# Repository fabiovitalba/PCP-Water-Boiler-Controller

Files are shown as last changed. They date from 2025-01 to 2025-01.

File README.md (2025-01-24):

# Fabio Vitalba - Arduino Water Boiler Controller ('Boil Voyage')
This is the final project for the course "Physical Computing Project 24/25" for Fabio Vitalba.

## Boil Voyage
The Project is divided into two repositories. This repository is the Arduino Controller that controls the 3D world created in Unity.
Find the other repository here: [Ship Navigation Project (Boil Voyage)](https://github.com/fabiovitalba/PCP-Ship-Project).

## 1. Description
This Arduino Project consists in the arduino script that handles the Water Boiler Controller. It reads from three different sensors/resistors:
- A **rotary potentiometer** that is hidden in the bottom part of the water boiler. It is used in order to read the rotation of the water boiler.
- A **photocell** that is placed inside the water boiler in order to read the amount of light shining into the inside of the water boiler. This is used to measure how much light is led in by the water boiler lid.
- A **switch** directly taken from the water boiler circuit. The switch consists in a broken circuit that closes whenever the button on the handle of the water boiler is closed.

These inputs are used to produce the following outputs:
- **SensorAbsoluteRotationValue**: The raw output produced by the rotary potentiometer, filtered using EMA (Exponential Moving Average).
- **AbsoluteRotationValue**: The absolute rotation of the water boiler. This is the processed output produced by the rotary potentiometer.
- **RelativeRotationValue**: The rotation of the water boiler, relative to its starting position. The starting position is also continuously updated, so that anytime the user reverses the rotation, that reversal is immediately effective.
- **SwitchValue**: The output produced by the switch circuit. Whenever the switch is not being pressed this will be 0. However, when the switch is being pressed, the circuit closes and the value will raise.
- **SensorLightValue**: The raw output produced by the photocell.
- **LightValue**: The output produced by the photocell. Whenever the lid is closed a base-amount of light is entering the water boiler from the sidewalls. Once the lid is opened (even when only partially open), more light enters and the output of the photocell will raise.

## 2. Visuals
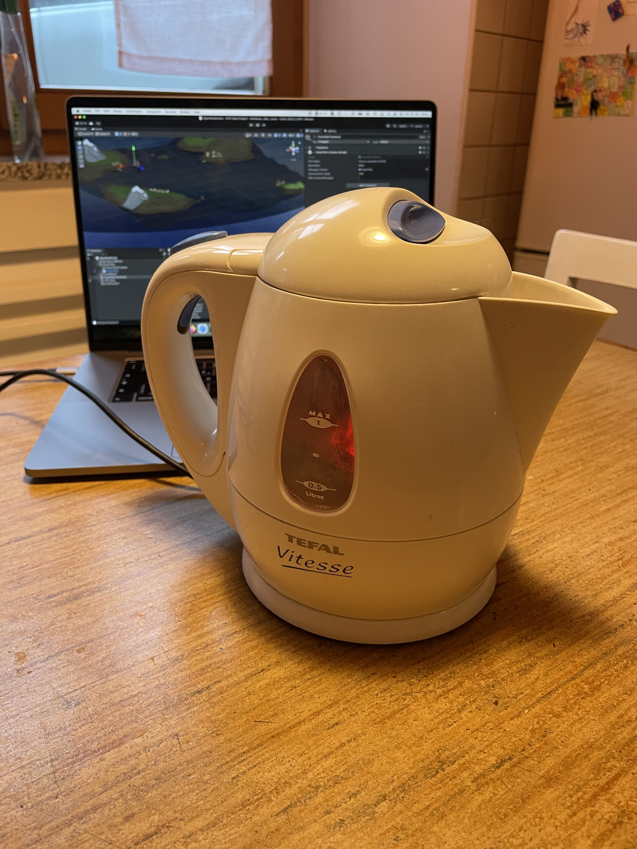
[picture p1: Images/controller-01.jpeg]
Image of the Controller package

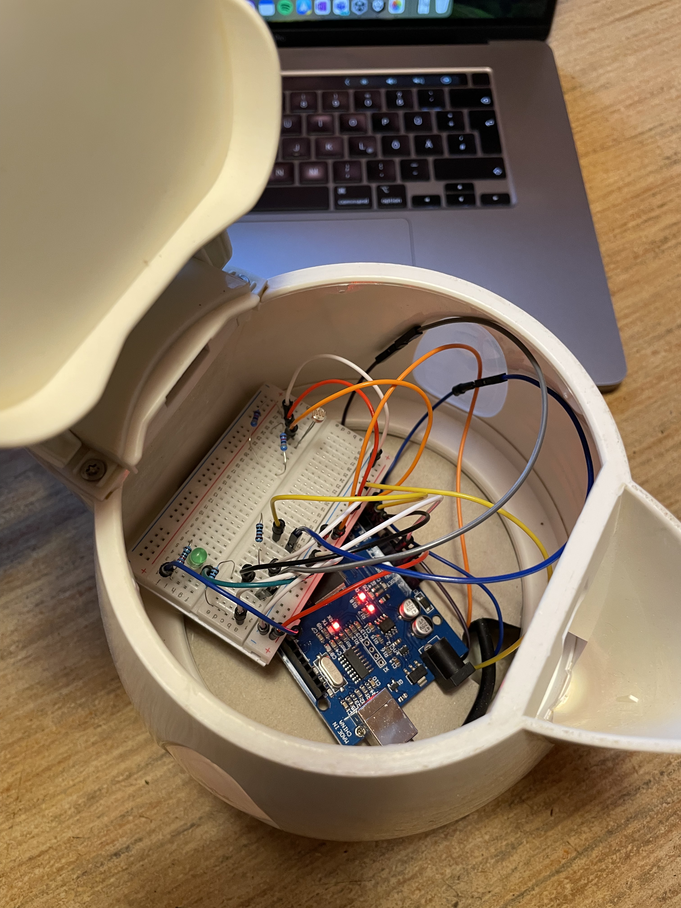
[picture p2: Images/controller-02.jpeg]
Image of the Controller insides

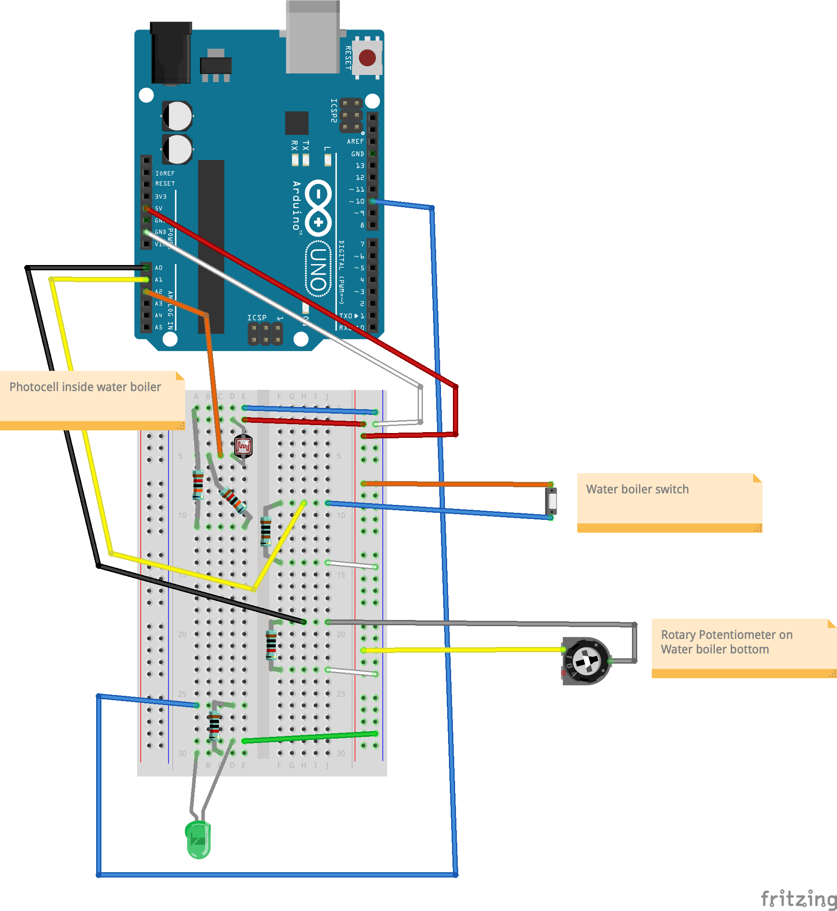
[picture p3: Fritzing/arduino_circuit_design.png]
Circuit design in fritzing


Find some more detailed images of the [build process](/BUILDHISTORY.md).

## 3. Installation
The Water Boiler Controller can be used as is, but should be tuned based on the environment it's being used in. The arduino script contains a few constants that should be tuned based on the baseline values you might find during usage.

### 3.1. Rotation settings
_In order to tune these settings, listen to the Arduino on the Serial Port (default is 9600). Open the Serial Plotter, then continue._
- `MIN_ROTATION_VALUE`: Rotate the water boiler completely to the left. Read the value for `SensorAbsoluteRotationValue` and set the constant `MIN_ROTATION_VALUE` to this value. (Rounding the value up a little is fine.)
- `MAX_ROTATION_VALUE`: Rotate the water boiler completely to the right. Read the value for `SensorAbsoluteRotationValue` and set the constant `MIN_ROTATION_VALUE` to this value. (Rounding the value down a little is fine.)
- `MAX_REL_ROTATION_VALUE`: This value defines the maximum rotation value before the relative starting position is moved in the rotation direction. A higher value means that rotations are harder to reverse, a smaller value means that rotations are quick to reverse. Default value is `40`.

### 3.2. Switch settings
_In order to tune these settings, listen to the Arduino on the Serial Port (default is 9600). Open the Serial Plotter, then continue._
- `SWITCH_TRIGGER_VALUE`: This is the minimum value for the Switch Circuit to count as "triggered". Usually the switch - in unpressed mode - should have a value of 0, so anything above 0 should mean that the switch is triggered. To avoid unwanted behaviour, we set a theshold in order to be sure that the switch was triggered correctly. Default value is `300`.

### 3.3. Light settings
_In order to tune these settings, listen to the Arduino on the Serial Port (default is 9600). Open the Serial Plotter, then continue._
- `MIN_LIGHT_VALUE`: Place the water boiler in the position you want to use it and close the water boiler lid. Read the value for `SensorLightValue` and set the constant `MIN_LIGHT_VALUE` to this value. It is a good idea to add 10-20 to the constant's value to account for slight lighting variations.
- `MAX_LIGHT_VALUE`: Place the water boiler in the position you want to use it and open the water boiler lid completely. Read the value for `SensorLightValue` and set the constant `MAX_LIGHT_VALUE` to this value. (Rounding the value down a little is fine.)

## 4. Usage
The Water Boiler Controller emits the following values on the Serial Port (default 9600):
- **AbsoluteRotationValue**: Provides a value between `-127` and `127` to indicate the absolute rotation position for the rotary potentiometer. The value `127` is at the outer left maximum, while the value `-127` is at the outer right maximum.
- **RelativeRotationValue**: Provides a value between `-MAX_REL_ROTATION_VALUE` and `MAX_REL_ROTATION_VALUE` relative to the starting position of the controller. Negative value indicate a rotation to the right, positive a rotation to the left.
- **SwitchValue**: Provides a value between `0` and `1`. Anything that is above `SWITCH_TRIGGER_VALUE` activates the internal LED and should be counted as triggered/active.
- **LightValue**: Provides a value between `0` and `255`. The higher the value, the more light is entering the water boiler.

Sample output: `SensorAbsoluteRotationValue:473.00,AbsoluteRotationValue:-31,RelativeRotationValue:0,SwitchValue:0,SensorLightValue:519.00,LightValue:0`

## 5. Support
For issues feel free to contact me on fvitalba@unibz.it, or by opening an Issue on the Repository.

## 6. Contributing
Currently this project is not open for contributions at it is in very early stages of development.

## 7. Authors and acknowledgment
- Main author: Fabio Vitalba

## 8. License
MIT License
Copyright (c) 2025 Fabio Vitalba

## 9. Project status
This Project is currently being worked on.

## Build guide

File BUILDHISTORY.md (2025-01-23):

# Build History
This photoseries gives a little insight into the build process of the water boiler controller.

### Reassembled water boiler
I removed all the insides from the water boiler and the heating circuit. The switch circuit was partially kept and cables were soldered on. The rotar potentiometer was glued to the underside of the water boiler switch.
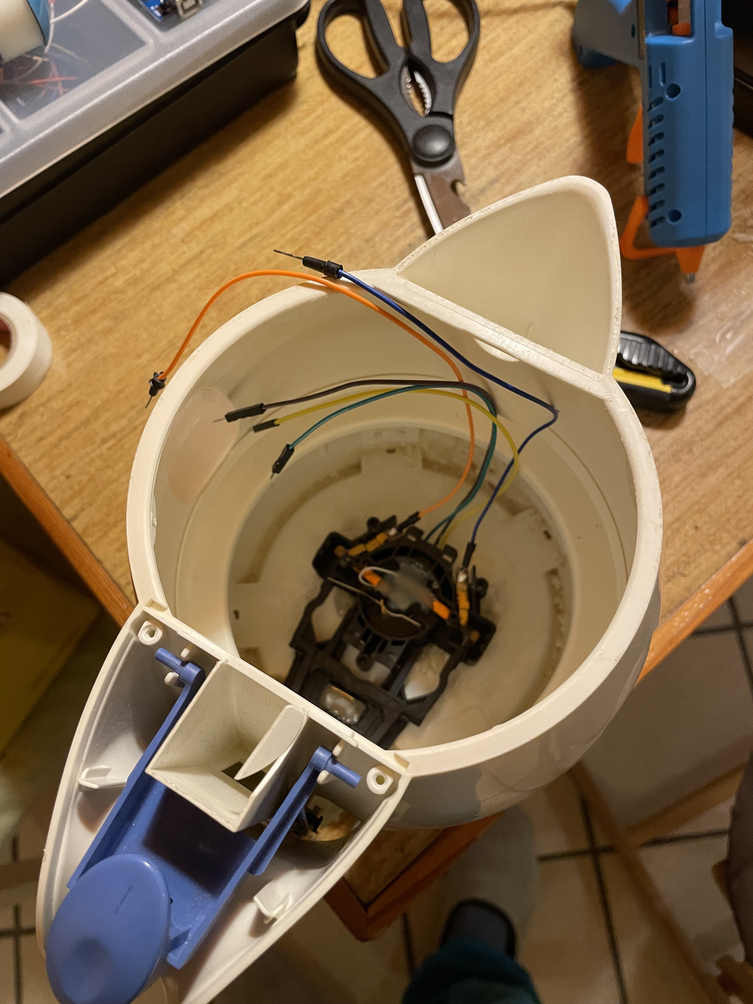
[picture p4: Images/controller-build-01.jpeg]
Reassembled water boiler with switch and rotary potentiometer


### Rotary potentiometer at the bottom
The rotary potentiometer was placed at the bottom of the water boiler instead of its power supply. Two wires were put in place in order to give the potentiometer something to hold on to. The wires were later glued in place to avoid them falling out.
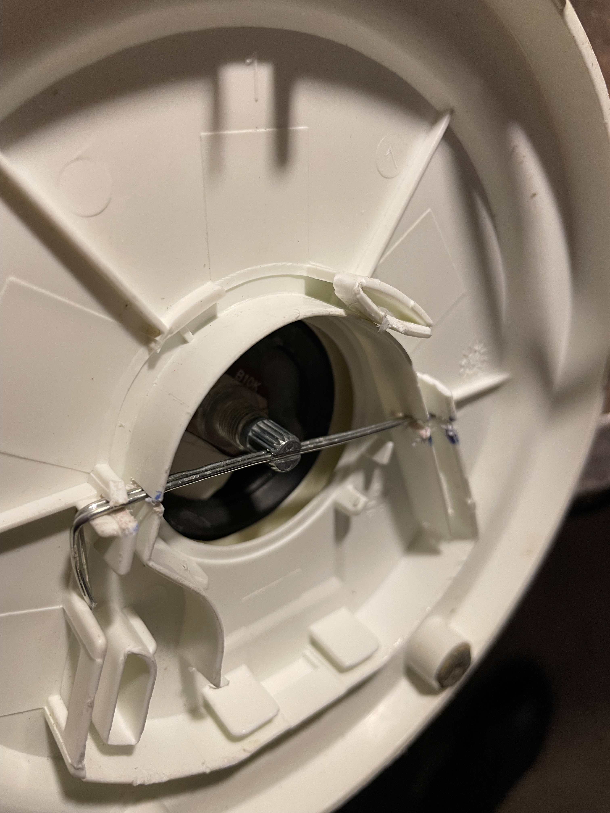
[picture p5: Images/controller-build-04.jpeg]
Rotary potentiometer at the bottom


### Water boiler switch circuit
The water boiler switch circuit is very simple as it uses a plastic lever to connect the copper contacts to close the circuit. Two cables were soldered onto the copper contacts in order to read the closing of this circuit whenever the button closes.
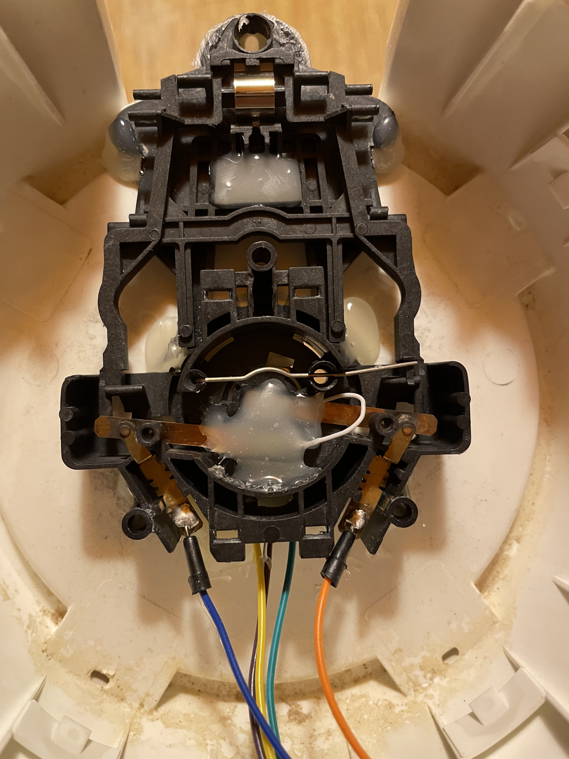
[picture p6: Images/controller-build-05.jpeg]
Water boiler switch circuit


### Arduino prototyping
The arduino was connected with the rotary potentiometer, and the switch in order to test first outputs.
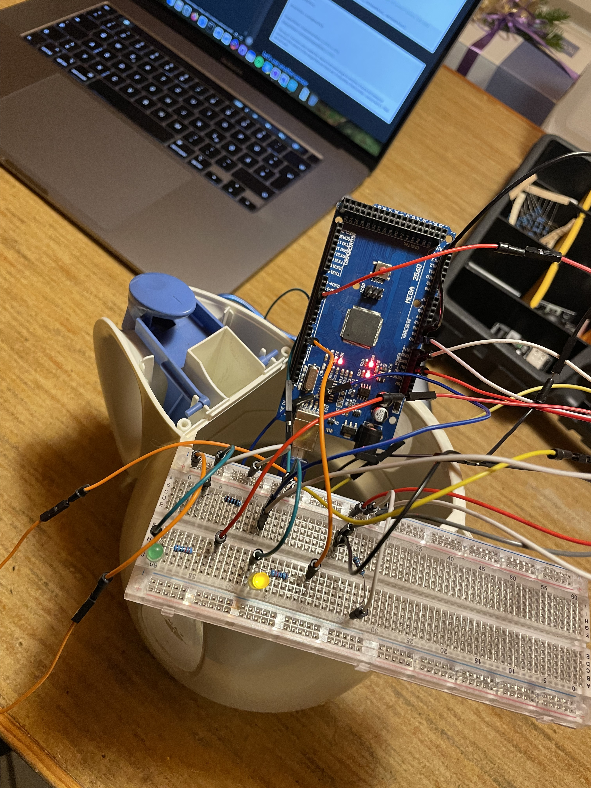
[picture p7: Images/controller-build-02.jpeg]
Prototyping with Arduino


### USB cable positioning
The USB cable was positioned at the very bottom of the water boiler handle in order to achieve a clean look, without immediately giving away the insides.
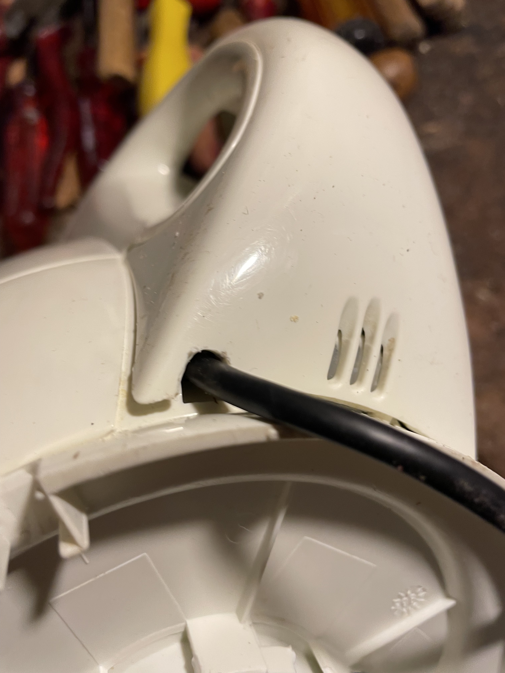
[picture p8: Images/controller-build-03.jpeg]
USB cable exit on water boiler


### Water boiler insides cleanup
Instead of the water boilers aluminium plate, which could not be kept since it contained the heating circuit and was simply too large, a cardboard piece was placed to hide the switch and provide a layer for the arduino to sit on.
Cables are funneled from the bottom through a small hole in the cardboard.
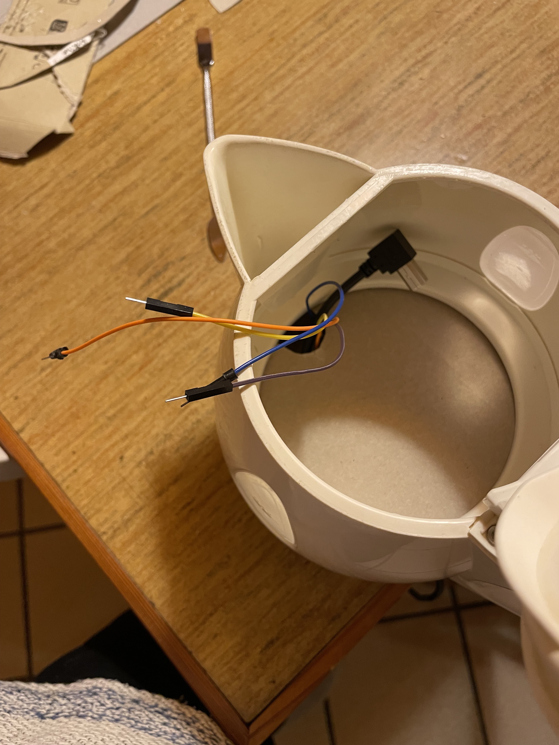
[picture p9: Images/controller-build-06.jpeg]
Cardboard layer to hide switch


### Arduino placed on the inside
The Arduino is placed on the cardboard layer and connected with a mini breadboard that contains all the necessary circuits to read the outputs. A photocell was added in order to read the incoming light and provide additional outputs.
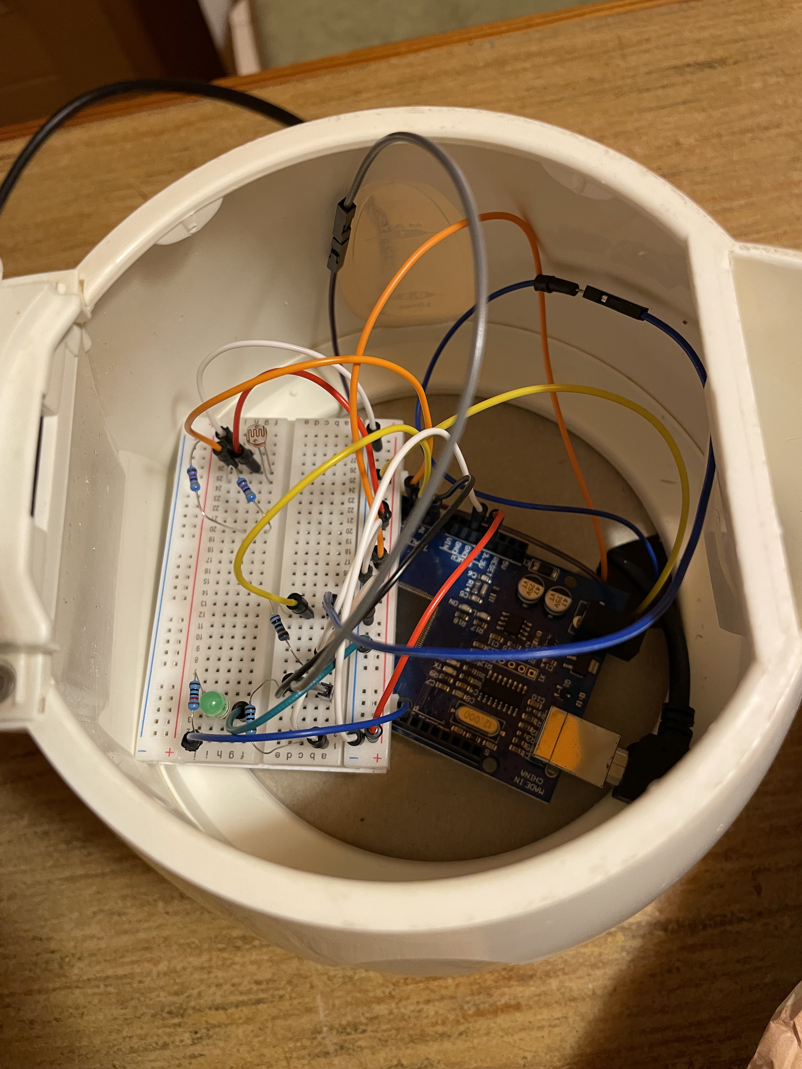
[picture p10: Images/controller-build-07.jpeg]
Arduino placed on the inside


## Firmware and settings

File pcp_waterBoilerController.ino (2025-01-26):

/// LAYOUT BASED PARAMETERS ///
const int SWITCH_PIN = A1;
const int ROTATION_PIN = A0;
const int LIGHT_PIN = A2;
const int LED_PIN = 10;


/// ENVIRONMENT RELATIVE PARAMETERS ///
// Values read by analog pins are voltages between 0V and 5V.
// 0V corresponds to 0 and 5V corresponds to 1023.
const int MIN_ROTATION_VALUE = 380;
const int MAX_ROTATION_VALUE = 640;
const int MAX_REL_ROTATION_VALUE = 40;

// The switch can assume values between 0 and ~600-700.
// We assume that a minimum value (like 300) has to be met in order to count as active.
const int SWITCH_TRIGGER_VALUE = 300;

// In absolute darkness the light sensor still return about ~500 (~580 with the lid closed) as a value.
// At maximum brightness the light sensor reaches about ~660  (with the lid open and beneath a lamp).
const int MIN_LIGHT_VALUE = 580;
const int MAX_LIGHT_VALUE = 660;


/// RELATIVE PARAMETERS ///
int startingRotationValue = 0;


/// FILTER PARAMETERS ///
const float ALPHA = 0.1f; // The higher the value, the more we weigh recently read data.
int emaFilteredValue = 0;


void setup() {
  pinMode(SWITCH_PIN, INPUT);
  pinMode(ROTATION_PIN, INPUT);
  pinMode(LIGHT_PIN, INPUT);
  pinMode(LED_PIN, OUTPUT);
  Serial.begin(9600);

  // Reset switch indicator LED to off
  digitalWrite(LED_PIN, LOW);

  // Store the Starting Position for the variable resistor in order to be able to use the controller without
  // any particular starting position.
  emaFilteredValue = analogRead(ROTATION_PIN);
  startingRotationValue = getRotationValueFromSensorValue(emaFilteredValue);
}

void loop() {
  // We read the variable resistors value in order to understand the water boilers position.
  int absoluteSensorValue = analogRead(ROTATION_PIN);
  int absoluteRotationValue = getRotationValueFromSensorValue(applyEmaFilter(absoluteSensorValue));

  // We use the Relative Rotation Value in order to ignore the starting position of the variable resistor.
  // A rotation to the left is translated into a positive value and a rotation to the right becomes a negative value.
  int relativeRotationValue = startingRotationValue - absoluteRotationValue;
  // If the Rotation Value exceeds a set maximum, then we adjust the starting rotation point. This is in order to never exceed the maximum
  // relative rotation value.
  if (abs(relativeRotationValue) > MAX_REL_ROTATION_VALUE) {
    if (relativeRotationValue < 0) {
      startingRotationValue += (abs(relativeRotationValue) - MAX_REL_ROTATION_VALUE);
    } else {
      startingRotationValue -= (abs(relativeRotationValue) - MAX_REL_ROTATION_VALUE);
    }
    relativeRotationValue = startingRotationValue - absoluteRotationValue;
  }

  // We read the value from the Water Boiler built-in switch and light the led as an indicator.
  int switchValue = analogRead(SWITCH_PIN);
  if (switchValue >= SWITCH_TRIGGER_VALUE) {
    switchValue = 1;
    digitalWrite(LED_PIN, HIGH);
  } else {
    switchValue = 0;
    digitalWrite(LED_PIN, LOW);
  }

  // We read the light reactive resistor's value in order to understand how far the water boilers lid
  // is opened.
  int sensorLightValue = analogRead(LIGHT_PIN);
  int lightValue = getLightValueFromSensorValue(sensorLightValue);

  Serial.print("SensorAbsoluteRotationValue:"); Serial.print(emaFilteredValue); // For debugging & fine tuning
  Serial.print(",");
  Serial.print("AbsoluteRotationValue:"); Serial.print(-absoluteRotationValue);
  Serial.print(",");
  Serial.print("RelativeRotationValue:"); Serial.print(relativeRotationValue);
  Serial.print(",");
  Serial.print("SwitchValue:"); Serial.print(switchValue);
  Serial.print(",");
  Serial.print("SensorLightValue:"); Serial.print(sensorLightValue); // For debugging & fine tuning
  Serial.print(",");
  Serial.print("LightValue:"); Serial.print(lightValue);
  Serial.println();
  delay(50);
}

int clampIntToIntRange(int inputValue, int minIn, int maxIn, int minOut, int maxOut) {
  int clampedValue = map(inputValue, minIn, maxIn, minOut, maxOut);
  clampedValue = constrain(clampedValue, minOut, maxOut);
  return clampedValue;
}

int getRotationValueFromSensorValue(int sensorValue) {
  return clampIntToIntRange(sensorValue, MIN_ROTATION_VALUE, MAX_ROTATION_VALUE, -127, 127);
}

int getLightValueFromSensorValue(int sensorValue) {
  return clampIntToIntRange(sensorValue, MIN_LIGHT_VALUE, MAX_LIGHT_VALUE, 0, 255);
}

int applyEmaFilter(int rawInput) {
  emaFilteredValue = (ALPHA * rawInput) + ((1.0f - ALPHA) * emaFilteredValue);
  return emaFilteredValue;
}

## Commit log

2025-01-23 Add circuit design in fritzing
    [arduino_circuit_design.fzz]
2025-01-24 Fix readme and add analog outputs for controller
    [pcp_waterBoilerController.ino]
2025-01-24 Add EMA filter for rotation values (#1)
    * WIP - Testing EMA and Average filters
    * Use EMA filter to smoothen spikes in rotation values
    * Update readme
    * Code cleanup and filter tuning
    * Update readme
2025-01-25 Fix value inversion for AbsoluteRotationValue
    [pcp_waterBoilerController.ino]
2025-01-26 Fix ema filter and change floats to int
    [pcp_waterBoilerController.ino]
2025-01-26 Fix EMA filter for rotation value
    [pcp_waterBoilerController.ino]
2025-01-26 Add comment for analog sensor value interpretation
